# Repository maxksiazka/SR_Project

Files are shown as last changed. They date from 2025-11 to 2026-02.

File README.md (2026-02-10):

# SR_Project
## Autonomous Robotic ENgineered Takedown Machine
---
### Opis projektu

Projekt obejmuje zrealizowanie mobilnego robota typu [mini-sumo](https://kcir.pwr.edu.pl/~mucha/Pracki/Michal_Piotrowicz_praca_inzynierska.pdf).
Mechanika projektu znajduje się w podfolderze *Mechanics/*, podczas gdy projekt KiCad elektroniki układu znajduje się w podfolderze *Electronics/*.
Oprogramowanie robota mobilnego znajduje się w podfolderze *sumo/*.

---

### Elementy składowe robota

- MCU: **Raspberry Pi Pico 2 WH**
- Time-of-Flight Sensor: **VL53L0X**
- Czujnik odbiciowy: **KTIR0711S**
- Sterownik silników (H-bridge): **TB6612FNG**
- Silniki: **N20-BT37 micro X:1**
- Moduł Wi-Fi: zintegrowany z MCU.
- Zasilanie: **Li-Po 2S**

---

### Zadania projektowe 

**Kolejność na liście zadań nie jest wiążąca.**
 - [x] Wykonanie wstępnego projektu mechaniki robota.
 - [x] Wykonanie projektu elektroniki robota.
 - [x] Zakup elementów elektronicznych.
 - [x] Wydrukowanie wstępnego korpusu robota.
 - [x] Wydrukowanie wstępnych kół robota
 - [x] Napisanie prostego klienta TCP - 'echo'.
 - [x] Napisanie systemu kontroli silników - kontrola PWM.
 - [x] Napisanie prostego systemu sterowania: klient TCP -> PWM.
 - [x] Implementacja odbioru danych z TOF - komunikacja I^2^C.
 - [x] Implementacja odbioru danych z czujników odbiciowych - ADC.
 - [x] Implementacja autonomicznego systemu sterowania
 - [ ] (Opcjonalnie, ale prawie na pewno) Refactoring kodu.
 - [x] Finalizacja projektu korpusu.
 - [x] Finalizacja projektu kół.
 - [x] Pożar robota
 - [ ] Integracja robota.
 ---
 ---

## Metodyka Pracy
Pracujemy z użyciem `git branch` - PROSŻĘ

Standardowo merge request po *weryfikacji dwuosobowej*.

Coś jak [tutaj](https://www.geeksforgeeks.org/git/best-git-practices-to-follow-in-teams/) jeżeli chodzi o zasady to by była moja propozycja.

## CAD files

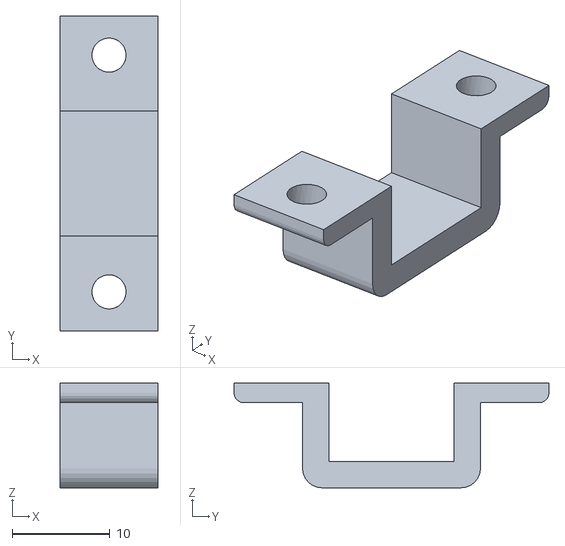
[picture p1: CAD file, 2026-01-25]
Mechanics/konsola_silniki.stl
10.0 x 32.2 x 10.7

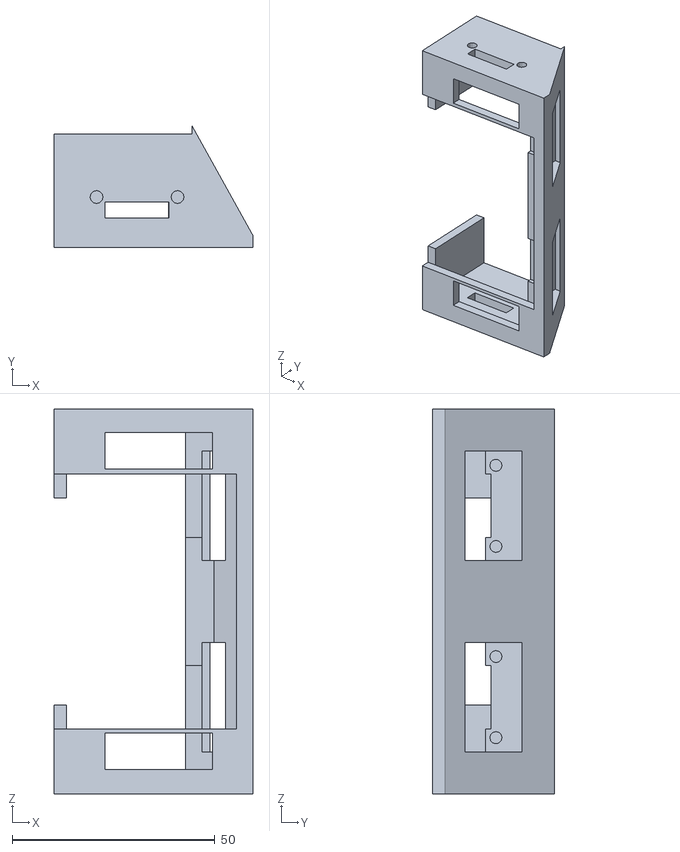
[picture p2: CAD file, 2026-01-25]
Mechanics/korpus.stl
49.0 x 30.0 x 95.0

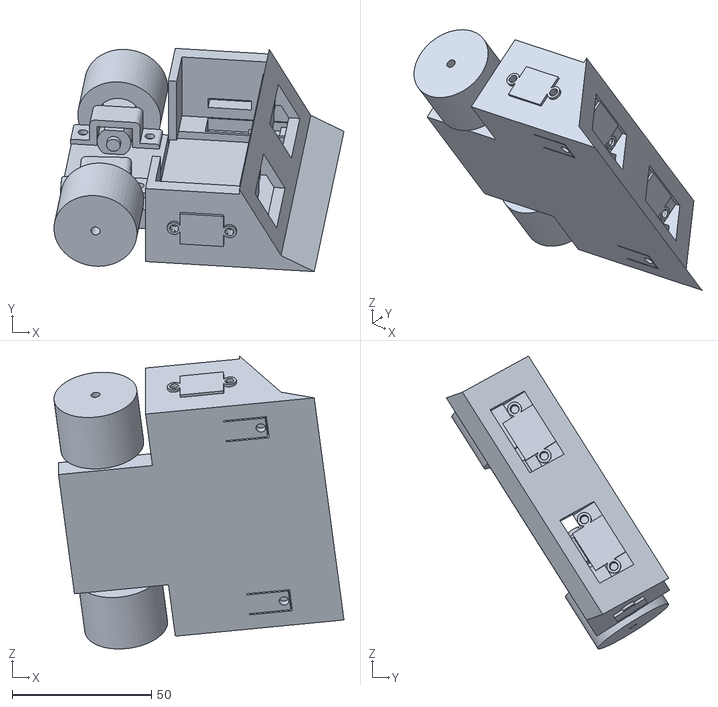
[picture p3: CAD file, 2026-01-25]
Mechanics/arent.stl
104.2 x 80.2 x 105.3

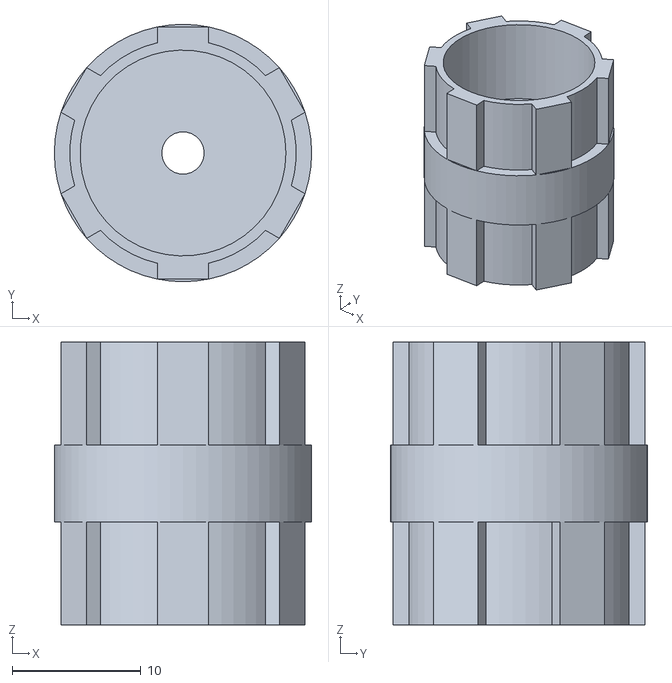
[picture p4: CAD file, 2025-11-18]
Mechanics/kola.stl
20.0 x 20.0 x 22.0

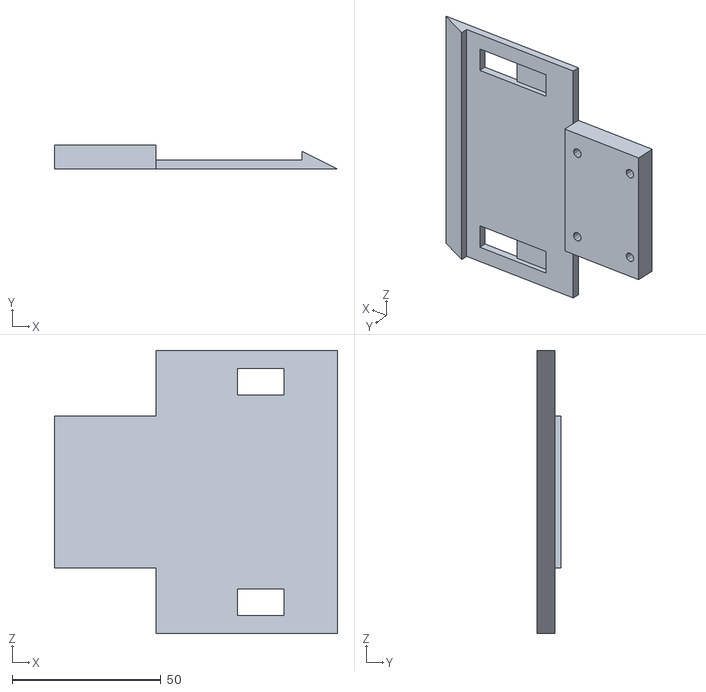
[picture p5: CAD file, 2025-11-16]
Mechanics/platforma.stl
95.0 x 8.00 x 95.0

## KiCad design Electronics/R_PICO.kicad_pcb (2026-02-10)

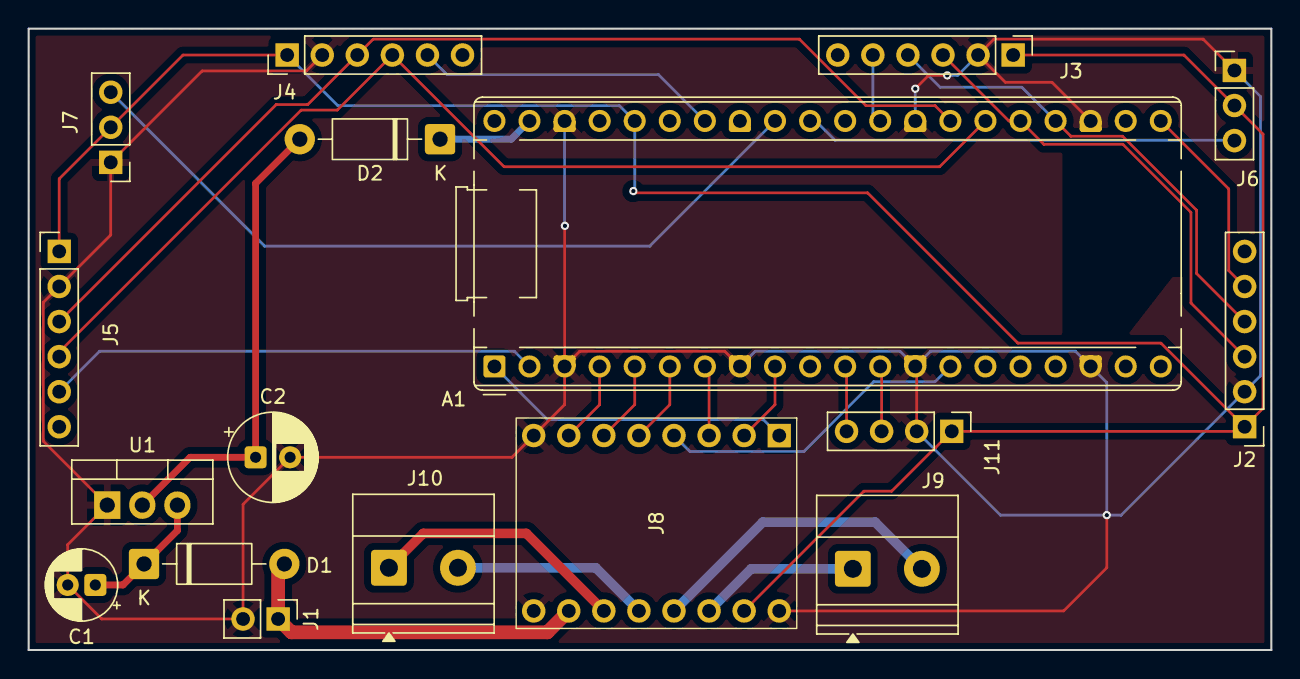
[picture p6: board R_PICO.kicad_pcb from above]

Board: 2 copper layers, 90.0 x 45.0 mm, 17 parts (0 on the bottom side), 29 nets.

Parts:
A1: RaspberryPi_Pico_W; RaspberryPi_Pico_Common_THT
C1: 10u; CP_Radial_D5.0mm_P2.00mm
C2: 100u; CP_Radial_D6.3mm_P2.50mm
D1, D2: 1N5819; D_DO-41_SOD81_P10.16mm_Horizontal
J1: Battery_Connector; PinHeader_1x02_P2.54mm_Vertical
J2, J3, J4, J5: VL53L0X; PinHeader_1x06_P2.54mm_Vertical
J6, J7: KTIR0711S; PinHeader_1x03_P2.54mm_Vertical
J8: TB6612FNG; TB6612FNG_Polulu_Breakout
J9: MotorL; TerminalBlock_Phoenix_MKDS-1,5-2_1x02_P5.00mm_Horizontal
J10: MotorR; TerminalBlock_Phoenix_MKDS-1,5-2_1x02_P5.00mm_Horizontal
J11: Starter; PinHeader_1x04_P2.54mm_Vertical
U1: LM1117T-5.0; TO-220-3_Vertical

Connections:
/2S: D1.2 (A), J1.1 (BAT+), J8.10 (VMOT)
/3V3: A1.36 (3V3), J2.1 (VCC), J3.1 (VCC), J4.1 (VCC), J5.1 (VCC), J6.2 (VCC), J7.2 (VCC), J8.15 (VCC), J11.1 (VCC)
/5V: C2.1, D2.2 (A), U1.2 (VO)
/A1: A1.7 (GPIO5), J8.3 (AIN1)
/A2: A1.9 (GPIO6), J8.2 (AIN2)
/ADC0: A1.31 (GPIO26_ADC0), J6.3 (OUT)
/ADC1: A1.32 (GPIO27_ADC1), J7.3 (OUT)
/B1: A1.6 (GPIO4), J8.5 (BIN1)
/B2: A1.5 (GPIO3), J8.6 (BIN2)
/GP10: A1.14 (GPIO10), J8.4 (STBY)
/KILL: A1.11 (GPIO8), J11.4 (KILL)
/MOT1_IN: J8.14 (AO1), J9.1
/MOT1_OUT: J8.13 (AO2), J9.2
/MOT2_IN: J8.11 (BO1), J10.1
/MOT2_OUT: J8.12 (BO2), J10.2
/PWM0A: A1.1 (GPIO0), J8.1 (PWMA)
/PWM1A: A1.4 (GPIO2), J8.7 (PWMB)
/SCL1: A1.25 (GPIO19), J2.3 (SCL), J3.3 (SCL)
/SDA1: A1.24 (GPIO18), J2.4 (SDA), J3.4 (SDA)
/START: A1.12 (GPIO9), J11.3 (START)
/XSHUT_FRONT_LEFT: A1.34 (GPIO28_ADC2), J4.5 (XSHUT)
/XSHUT_FRONT_RIGHT: A1.29 (GPIO22), J3.5 (XSHUT)
/XSHUT_LEFT: A1.2 (GPIO1), J5.5 (XSHUT)
/XSHUT_RIGHT: A1.21 (GPIO16), J2.5 (XSHUT)
/out: A1.39 (VSYS), D2.1 (K)
/scl0: A1.27 (GPIO21), J4.3 (SCL), J5.3 (SCL)
/sda0: A1.26 (GPIO20), J4.4 (SDA), J5.4 (SDA)
GND: A1.3 (GND), A1.8 (GND), A1.13 (GND), A1.18 (GND), A1.23 (GND), A1.28 (GND), A1.38 (GND), C1.2, C2.2, J1.2 (BAT-), J2.2 (GND), J3.2 (GND), J4.2 (GND), J5.2 (GND), J6.1 (GND), J7.1 (GND), J8.8 (GND), J8.9 (GND), J8.16 (GND), J11.2 (GND), U1.1 (GND)
unnamed: C1.1, D1.1 (K), U1.3 (VI)

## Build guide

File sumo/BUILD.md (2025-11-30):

# Build guide for SR_Project/sumo

## Linux

1. Install [build prerequisites](#build-prerequisites) on your system
2. `git clone https://github.com/maxksiazka/SR_Project`
3. `cd SR_Project/sumo`
4. `mkdir build; cd build`
5. `cmake ..`
6. `make`
7. Copy the `sumo.uf2` binary to your Pico

**Notes:**
 - This build process does not rely on the Pico VSCode extension.
 - The build process relies on environment variable PICO_SDK_PATH - if you're using the VSCode extension for Pico, said variable needs to be set manually.
 - It is heavily advised to have a somewhat recent version of arm-none-eabi-gcc.
 - It also needs the [picotool](https://github.com/raspberrypi/picotool) binary to be in PATH.
 - The TCP server necessary for connecting to the Pico is NOT provided.

## Windows

**Unsupported**
*I use arch, btw*

## Build prerequisites

- arm-none-eabi-gcc
- [pico_sdk](https://github.com/raspberrypi/pico-sdk)
- [picotool](https://github.com/raspberrypi/picotool)

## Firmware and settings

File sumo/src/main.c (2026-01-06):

#include "main.h"
#include "pwm_motor_control.h"
#include "tcp_api_implementation.h"
#include "adc_line_detector.h"
#include <pico/cyw43_arch.h>
#include <pico/stdlib.h>
#include "tof_i2c.h"

bool test_tcp(void) {
    DEBUG_printf("TCP test function called.\n");
    TCP_CLIENT_T* tcp_client = tcp_client_init();
    if (tcp_client == NULL) {
        DEBUG_printf("Failed to initialize TCP client.\n");

        return false;
    }
    if (init_wifi_connection(WIFI_SSID, WIFI_PASSWORD) == false) {
        DEBUG_printf("Failed to initialize Wi-Fi connection.\n");
        tcp_client_close(tcp_client);
        return false;
    }
    DEBUG_printf("Wi-Fi connected.\n");
    DEBUG_printf("Connecting to TCP server at %s:%d...\n", TCP_SERVER_IP,
                 TCP_SERVER_PORT);
    if (tcp_client_open_connection(tcp_client) == false) {
        DEBUG_printf("Failed to open TCP connection.\n");
        tcp_client_close(tcp_client);
        return false;
    }
    DEBUG_printf("Connected to TCP server.\n");
    tcp_client->connected = true;
    cyw43_arch_gpio_put(LED_PIN, 1);
    while (tcp_client) {
        cyw43_arch_poll();
    }
    DEBUG_printf("TCP test function completed.\n");
    free(tcp_client);
    cyw43_arch_gpio_put(LED_PIN, 0);
    return true;
    
}

bool test_pwm_controlling(void) {
    cyw43_arch_gpio_put(LED_PIN, 1);
    DEBUG_printf("In test PWM\n");
    stdio_flush();
    pwm_control_init();
    DEBUG_printf("INIT DONE\n");
    stdio_flush();
    pwm_set_motor_dir(MOTOR_DIR_FORWARD);
    pwm_set_motor_speed(1, 50);
    pwm_set_motor_speed(2, 50);
    sleep_ms(5000);
    // pwm_set_motor_speed(1, 0);
    // pwm_set_motor_speed(2, 0);
    // pwm_set_motor_dir(MOTOR_DIR_STOP);
    return true;
}
bool test_tcp_with_pwm_control(void) {
    DEBUG_printf("TCP test function called.\n");
    TCP_CLIENT_T* tcp_client = tcp_client_init();
    if (tcp_client == NULL) {
        DEBUG_printf("Failed to initialize TCP client.\n");

        return false;
    }
    if (init_wifi_connection(WIFI_SSID, WIFI_PASSWORD) == false) {
        DEBUG_printf("Failed to initialize Wi-Fi connection.\n");
        tcp_client_close(tcp_client);
        return false;
    }
    DEBUG_printf("Wi-Fi connected.\n");
    DEBUG_printf("Connecting to TCP server at %s:%d...\n", TCP_SERVER_IP,
                 TCP_SERVER_PORT);
    if (tcp_client_open_connection(tcp_client) == false) {
        DEBUG_printf("Failed to open TCP connection.\n");
        tcp_client_close(tcp_client);
        return false;
    }
    DEBUG_printf("Connected to TCP server.\n");
    tcp_client->connected = true;
    cyw43_arch_gpio_put(LED_PIN, 1);

    pwm_control_init();
    pwm_set_motor_dir(MOTOR_DIR_FORWARD);
    pwm_set_motor_speed(1, 50);
    pwm_set_motor_speed(2, 50);

    adc_line_detector_init();
    while (tcp_client) {
        line_detector_status_t x = adc_check_line();
        cyw43_arch_poll();
        sleep_ms(100);
    }
    DEBUG_printf("TCP test function completed.\n");
    free(tcp_client);
    cyw43_arch_gpio_put(LED_PIN, 0);
    return true;
}

int main(void) {
    stdio_init_all();
    // test_tcp();
    // bool jd = test_pwm_controlling();
    test_tcp_with_pwm_control();
    if(!i2c_start()) {
        DEBUG_printf("Sensors execution failed.\n");
        return 1;
    }

    DEBUG_printf("Execution finished, entering infinite loop.\n");
    while (true) {
        sleep_ms(1000);
    }
    return 0;
}

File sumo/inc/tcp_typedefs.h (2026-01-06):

#ifndef TCP_TYPEDEFS_H
#define TCP_TYPEDEFS_H

// conditional definitions, since might be added in CMakeLists.txt
// #ifndef WIFI_SSID
// #define WIFI_SSID "HALNy-2.4G-001f85"
// #endif

// #ifndef WIFI_PASSWORD
// #define WIFI_PASSWORD "YtWWH9Lc3c"
// #endif

#ifndef TCP_SERVER_IP
#define TCP_SERVER_IP "192.168.34.11"
#endif

#ifndef TCP_SERVER_PORT
#define TCP_SERVER_PORT 5001
#endif

#ifndef TCP_BUF_SIZE
#define TCP_BUF_SIZE 2048
#endif

#include <lwip/tcp.h>

typedef enum {
    COMMAND_ECHO = 0,
    COMMAND_STOP = 1,
    COMMAND_FORWARD = 2,
    COMMAND_BACKWARDS = 3,
    COMMAND_LEFT = 4,
    COMMAND_RIGHT = 5,
    COMMAND_PIVOT_LEFT = 6,
    COMMAND_PIVOT_RIGHT = 7,
    COMMAND_UNDEFINED = 255,
} COMMAND_TYPE;

extern const char* COMMAND_TYPE_STRINGS[];

extern bool ECHO_MODE_ENABLED;
typedef struct TCP_CLIENT_T_ {
    struct tcp_pcb* tcp_pcb;
    ip_addr_t remote_addr;
    uint8_t buffer[TCP_BUF_SIZE];
    int32_t buffer_len;
    bool connected;
} TCP_CLIENT_T;

#endif // TCP_TYPEDEFS_H

/**
 * COMMAND_STOP
 * COMMAND_FORWARD
 * COMMAND_BACKWARDS
 * COMMAND_LEFT
 * COMMAND_RIGHT
 * ...
 */

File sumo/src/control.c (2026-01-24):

#include "control.h"
#include "VL53L0X_pico.h"
#include "adc_line_detector.h"
#include "pwm_motor_control.h"
#include "tof_i2c.h"

#define DISTANCE_THRESHOLD 600

static buffer_t buf[4];
static buffer_t* head;
static double mean_left;
static double mean_front_left;
static double mean_front_right;
static double mean_right;

void init_data_struct(void) {
    for (uint8_t i = 0; i < 3; ++i) {
        buf[i].next = &buf[(i + 1) % 3];
    }
    head = &buf[0];
}

void collect_data(void) {
    head->data.i2c_left = tofReadDistance(I2C_PORT_LEFT, I2C_LEFT);
    head->data.i2c_right = tofReadDistance(I2C_PORT_RIGHT, I2C_RIGHT);
    head->data.i2c_front_left = tofReadDistance(I2C_PORT_LEFT, I2C_FRONT_LEFT);
    head->data.i2c_front_right = tofReadDistance(I2C_PORT_RIGHT, I2C_FRONT_RIGHT);
    head->data.adc_left = adc_read_line(ADC_LINE_DETECTOR_PIN_LEFT);
    head->data.adc_right = adc_read_line(ADC_LINE_DETECTOR_PIN_RIGHT);
}

void calculate_mean(void) {
    buffer_t* buf1 = head->next;
    buffer_t* buf2 = buf1->next;
    buffer_t* buf3 = buf2->next;
    float alpha = 0.6;

    mean_left = tofReadDistance(I2C_PORT_LEFT, I2C_LEFT) * alpha + (1 - alpha) * mean_left;
    mean_front_left =
        tofReadDistance(I2C_PORT_LEFT, I2C_FRONT_LEFT) * alpha + (1 - alpha) * mean_front_left;
    mean_front_right =
        tofReadDistance(I2C_PORT_RIGHT, I2C_FRONT_RIGHT) * alpha + (1 - alpha) * mean_front_right;
    mean_right = tofReadDistance(I2C_PORT_RIGHT, I2C_RIGHT) * alpha + (1 - alpha) * mean_right;
    head = head->next;
}
enum MODE designate_strategy(void) {
    if (head->data.adc_left < 2000 || head->data.adc_right < 2000) {
        return SURVIVAL;
    }
    if (mean_front_left < DISTANCE_THRESHOLD || mean_front_right < DISTANCE_THRESHOLD) {
        return ATTACK;
    }
    return AQUISITION;
}
void begin_acquisition() {
    pwm_turn_clockwise();
}
bool acquire_target() {
    if (mean_front_left > mean_front_right) {
        pwm_pivot_counterclockwise();
    } else if (mean_front_left < mean_front_right) {
        pwm_pivot_clockwise();
    } else {
        pwm_set_motor_dir(MOTOR_DIR_FORWARD);
    }

    return true;
}
void predict_alignment() {

    pwm_set_motor_dir(MOTOR_DIR_FORWARD);
    // First, we calculate the difference between the left and right distances
    int16_t distance_diff = mean_left - mean_right;
    // Threshold to determine if RADICAL adjustment is needed
    const int16_t ALIGNMENT_THRESHOLD = 100; // in mm
    if (distance_diff > ALIGNMENT_THRESHOLD) {
        // coast left
        pwm_set_motor_speed(MOTOR_LEFT, 0);
        pwm_set_motor_speed(MOTOR_RIGHT, 100);
        return;
    } else if (distance_diff < -ALIGNMENT_THRESHOLD) {
        // coast right
        pwm_set_motor_speed(MOTOR_LEFT, 100);
        pwm_set_motor_speed(MOTOR_RIGHT, 0);
        return;
    }

    // we will need some equation to predict the alignment
    if (distance_diff > 10) {
        // Slightly closer on the right side, turn left
        pwm_set_motor_speed(MOTOR_LEFT, 70);
        pwm_set_motor_speed(MOTOR_RIGHT, 90);
    }

    else if (distance_diff < 10) {
        // Slightly closer on the left side, turn right
        pwm_set_motor_speed(MOTOR_LEFT, 90);
        pwm_set_motor_speed(MOTOR_RIGHT, 70);
    } else {
        // pieknie jest, cała naprzód
        pwm_set_motor_speed(MOTOR_LEFT, 100);
        pwm_set_motor_speed(MOTOR_RIGHT, 100);
    }
}

bool fight_mode_enable() {
    init_data_struct();
    enum MODE current_strategy = AQUISITION;
    begin_acquisition();
    pwm_set_motor_speed(MOTOR_LEFT, 80);
    pwm_set_motor_speed(MOTOR_RIGHT, 80);
    while (true) {
        collect_data();
        calculate_mean();
        current_strategy = designate_strategy();
        if (current_strategy == FIRST_CONTACT) {
            continue;
        }
        if (current_strategy == AQUISITION) {
            acquire_target();
            continue;
        }
        if (current_strategy == SURVIVAL) {
            pwm_set_motor_dir(MOTOR_DIR_BACKWARD);
            pwm_set_motor_speed(MOTOR_LEFT, 100);
            pwm_set_motor_speed(MOTOR_RIGHT, 100);
            sleep_ms(100);
            current_strategy = FIRST_CONTACT;
            begin_acquisition();
            continue;
        }

        predict_alignment();
    }
    return true;
}

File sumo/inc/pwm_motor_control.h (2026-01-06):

#ifndef PWM_MOTOR_CONTROL_H
#define PWM_MOTOR_CONTROL_H

#include "hardware/pwm.h"
#include "pico/stdlib.h"


#define PWM_MOTOR_1_GPIO 0
#define PWM_MOTOR_2_GPIO 2
#define MOTOR_LEFT PWM_MOTOR_1_GPIO
#define MOTOR_RIGHT PWM_MOTOR_2_GPIO
#define GPIO_MOTOR_1_PIN1 11
#define GPIO_MOTOR_1_PIN2 12
#define GPIO_MOTOR_2_PIN1 13
#define GPIO_MOTOR_2_PIN2 14

typedef enum MOTOR_DIR_ {
    MOTOR_DIR_STOP = 0,
    MOTOR_DIR_FORWARD = 1,
    MOTOR_DIR_BACKWARD = 2,
    MOTOR_DIR_LEFT = 3,
    MOTOR_DIR_RIGHT = 4
} MOTOR_DIR;

void pwm_control_init(void);

void pwm_set_motor_dir(MOTOR_DIR direction);

void pwm_set_motor_speed(uint8_t motor_id, uint8_t speed_percentage);

void pwm_pivot_clockwise(void);
void pwm_pivot_counterclockwise(void);
void pwm_turn_clockwise(void);
void pwm_turn_counterclockwise(void);
#endif // PWM_MOTOR_CONTROL_H

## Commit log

2025-11-16 Added mechanical schemes.
    [arent.stl, kola.stl, konsola_silniki.stl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]
2025-11-22 Revert bad commit
    This reverts commit 1a5bd893fcc986c2d9f44336ead459a8e4bed94c.
    [main.c, tcp_handling.c, tcp_typedefs.h]
2025-11-22 modified: CMakeLists.txt - Added new files modified: inc/lwipopts.h - used lwipopts_examples_common from pico-examples modified: inc/tcp_api_implementation.h - added print debugging modified: inc/tcp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
2025-11-23 Substituted printf calls with DEBUG_printf macro
2025-11-23 modified: CMakeLists.txt - Added compiler options, modified: inc/main.h - extracted LED_PIN and DEBUG_printf definitions, modified: inc/tcp_typedefs.h - forrmatting, modified: src/tcp_api_implementat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
2025-11-23 modified: CMakeLists.txt - removed incompatible compiler options
    modified: inc/tcp_typedefs.h - forrmatted
    modified: src/main.c - Tried to implement termination - client gets
    freed, and thats it
    modified: src/tcp_api_implementation.c - implemented send
    callback,modified close function
    [main.c, tcp_typedefs.h]
2025-11-23 modified: .gitignore - added vscode modified: sumo/inc/tcp_typedefs.h - changed to my router config modified: sumo/src/tcp_api_implementation.c - added error_callback
    [tcp_typedefs.h]
2025-11-23 modified: sumo/src/tcp_api_implementation.c - added connection callback and fixed error callback debug print
2025-11-30 Dodano projekt elektroniki, zaktualizowano README.md
    [R_PICO.kicad_pcb, R_PICO.kicad_sch]
2025-11-30 Created initialization of pwm modules, added new files to CMakeLists.txt
2025-11-30 simple control of motor over TCP/IP
2025-11-30 Update motor specification from 210:1 to 200:1
2025-12-12 added some i2c things for tof handle
2025-12-12 fixed CMake, abandoned static library project
    [adc_line_detector.c, main.c]
2025-12-12 corrected electronic schema, added adc support
    [R_PICO.kicad_sch]
2026-01-06 added helper defines to pwm_motor_control, added pivot functions to tcp_handling
2026-01-06 fixed missing directions in pwm_motor_control
    [pwm_motor_control.c, tcp_handling.c]
2026-01-16 added starter scheme
    [R_PICO.kicad_sch]
2026-01-24 updated electronics
    [R_PICO.kicad_sch]
2026-01-25 stage III mechanics
    [arent.stl, konsola_silniki.stl, korpus.stl]
2026-02-10 FIX: Changed Electronics schema
    Changed footprints of VL53L0X, KTIRs, and TB6612FNG. Amended electronics
    schema to match breakout boards.
    TODO: PCB schematic
    [R_PICO.kicad_pcb, R_PICO.kicad_sch]
2026-02-10 Feat: Finished PCB schematic, awaiting fabrication decision
    [R_PICO.kicad_pcb, R_PICO.kicad_sch]
2026-02-10 Update motor specification and project tasks
